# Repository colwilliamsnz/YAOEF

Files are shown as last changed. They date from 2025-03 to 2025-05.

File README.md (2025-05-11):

# YAOEF (Yet Another Open ESP Flasher)

## Status:

Tested. A PCB with this design has been built and tested.

## Introduction:

My remix of a simple "dongle" for flashing ESP32 based devices that have the ESPFlash header implemented (per Jon Oxer, SuperHouse. Ref http://superhouse.tv/espflash).

Why build USB capabilities into every ESP32 design when a simple header will suffice? Save on parts count, footprint, BOM, etc. The dongle supports auto-programming logic and a power switch allows it to be used for serial debugging when under circuit power (I.e., turn the switch off to disable USB power to ESPFlash header).

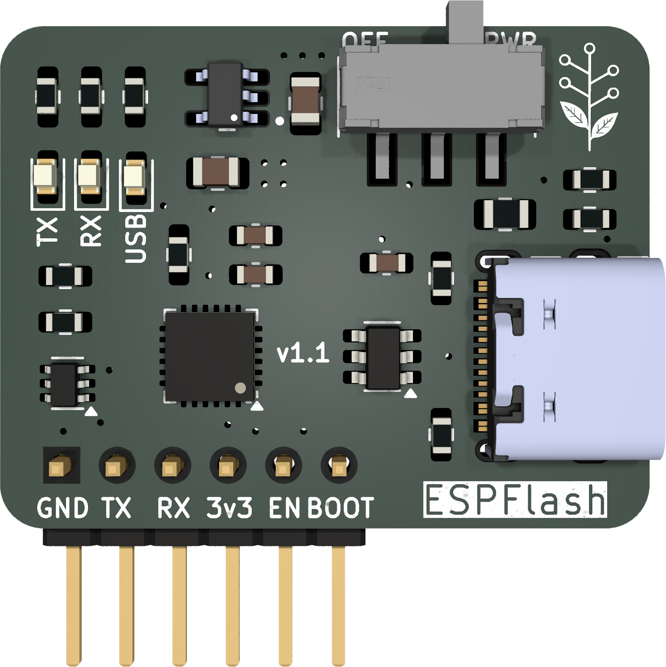
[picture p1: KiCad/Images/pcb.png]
Prototype


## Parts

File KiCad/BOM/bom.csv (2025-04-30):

Reference | Value | Footprint | Qty | Digikey_PN | Stocked
C1,C2 | 10u | Capacitor_SMD:C_0805_2012Metric | 2 | 490-6473-1-ND | Yes
C3,C5 | 100n | Capacitor_SMD:C_0603_1608Metric | 2 | 399-C0603C104K4RACTUCT-ND | Yes
C4 | 4.7u | Capacitor_SMD:C_0603_1608Metric | 1 | 1276-1784-1-ND
D1 | POWER | LED_SMD:LED_0603_1608Metric | 1 | 732-4978-1-ND | Yes
D2 | TX | LED_SMD:LED_0603_1608Metric | 1 | 732-4980-1-ND
D3 | RX | LED_SMD:LED_0603_1608Metric | 1 | 160-1434-1-ND
F1 | 6V 500mA | Fuse:Fuse_0805_2012Metric | 1 | 5923-0ZCK0050FF2ECT-ND
J1 | USB-C-16P (USB 2.0 only) | Wattle_Connectors:GCT_USB4105-GF-A-120 | 1 | 2073-USB4105-GF-A-120CT-ND
Q1 | MMDT3904 | Package_TO_SOT_SMD:SOT-363_SC-70-6 | 1 | 4786-MMDT3904CT-ND
R1 | 4k7 | Resistor_SMD:R_0603_1608Metric | 1 | 541-3993-1-ND | Yes
R2,R3 | 5k1 | Resistor_SMD:R_0603_1608Metric | 2 | 541-4030-1-ND
R4,R5,R6 | 1k | Resistor_SMD:R_0603_1608Metric | 3 | MCT0603-1.00K-MFCT-ND | Yes
R7,R8 | 10k | Resistor_SMD:R_0603_1608Metric | 2 | A121523CT-ND
R9 | 22k1 | Resistor_SMD:R_0603_1608Metric | 1 | 541-5271-1-ND
R10 | 47k5 | Resistor_SMD:R_0603_1608Metric | 1 | 541-4050-1-ND
S1 | JS102011SAQN | Wattle_Switches:SW_JS102011SAQN | 1 | 401-1999-1-ND
U1 | TLV75533PDBVR | Wattle_Regulators:TLV75533PDBVR | 1 | 296-50411-1-ND
U2 | USBLC6-4SC6 | Package_TO_SOT_SMD:SOT-23-6 | 1 | 497-4492-1-ND
U3 | CP2102N-Axx-xQFN24 | Package_DFN_QFN:QFN-24-1EP_4x4mm_P0.5mm_EP2.6x2.6mm | 1 | CP2102N-A02-GQFN24

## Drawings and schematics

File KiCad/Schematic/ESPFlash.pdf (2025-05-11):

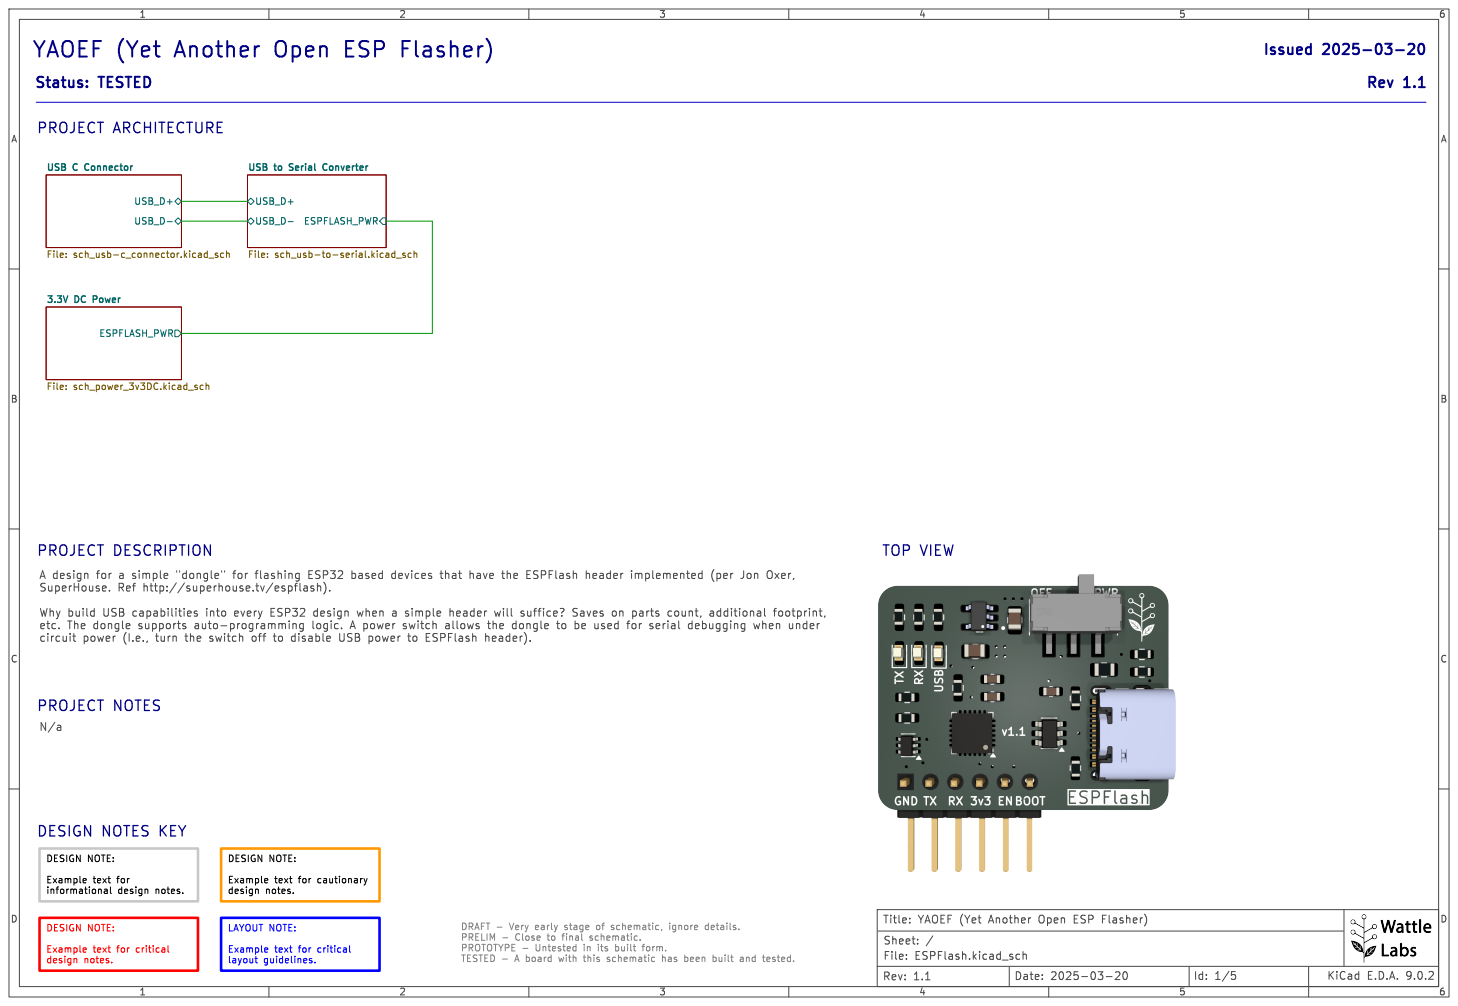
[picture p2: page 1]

3.3V DC Power File: sch_power_3v3DC.kicad_sch Revision History File: project history.kicad_sch

USB to Serial Converter File: sch_usb-to-serial.kicad_sch N/a

design notes. DESIGN NOTE: Example text for

DESIGN NOTE: Example text for cautionary

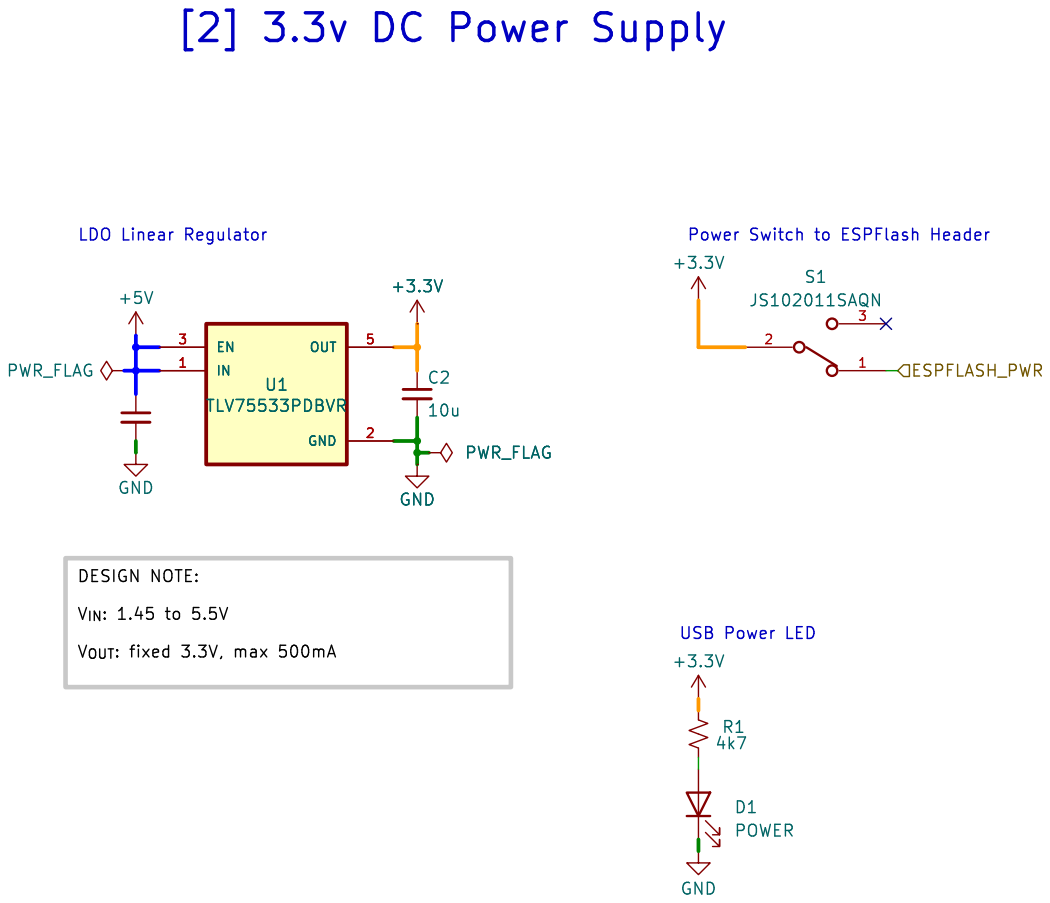
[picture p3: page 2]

DESIGN NOTE: V_{IN}:1.45 to 5.5V

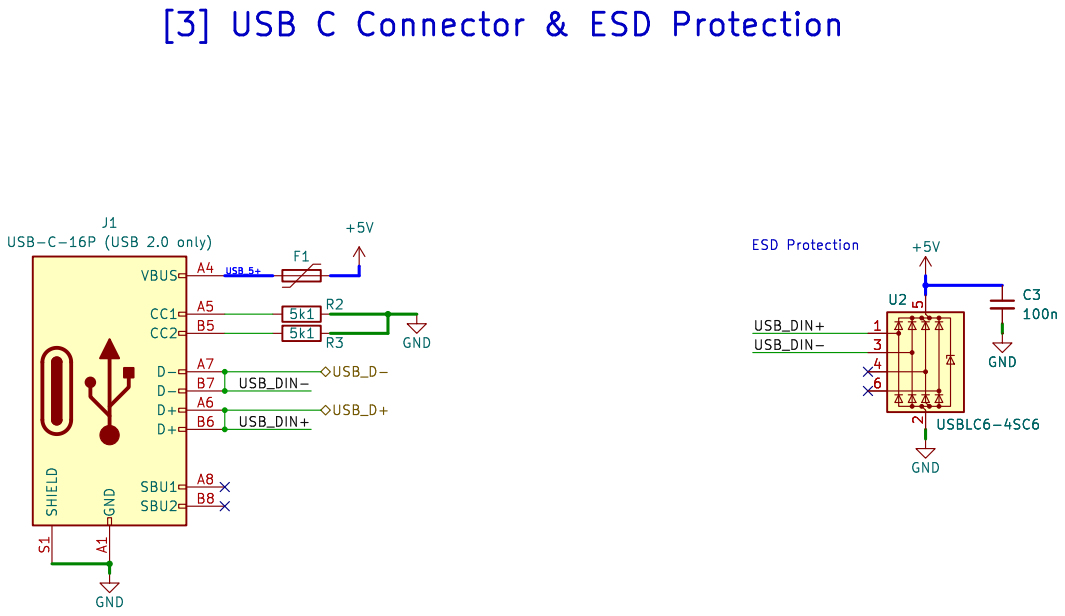
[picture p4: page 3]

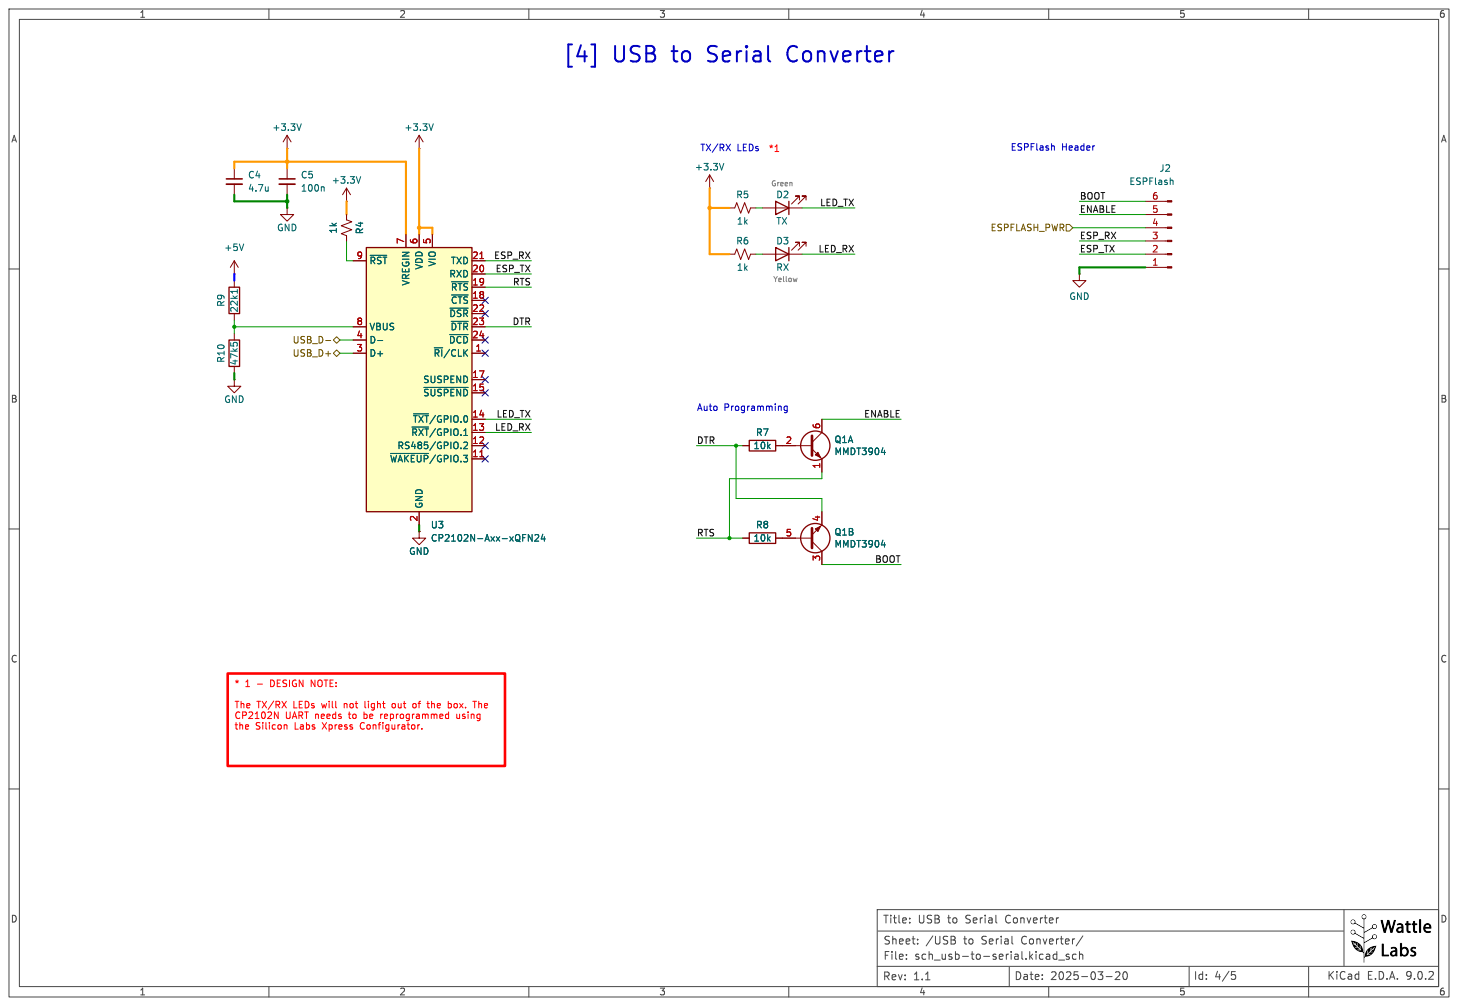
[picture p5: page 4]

TX/RX LEDs Auto Programming

5 TXD 21 RXD 20 ~{RTS} 19 ~{CTS} 18 ~{DSR} 22 ~{DTR} 23 ~{DCD} 24 ~{RI}/CLK1 SUSPEND 17 ~{SUSPEND}15 ~{TXT}/GPIO.014 ~{RXT}/GPIO.113 RS485/GPIO.2 12 ~{WAKEUP}/GPIO.311 U3 CP2102N-Axx-xQFN24 +3.3V GND GND

5 TXD 21 RXD 20 ~{RTS} 19 ~{CTS} 18 ~{DSR} 22 ~{DTR} 23 ~{DCD} 24 ~{RI}/CLK1 SUSPEND 17 ~{SUSPEND}15 ~{TXT}/GPIO.014 ~{RXT}/GPIO.113 RS485/GPIO.2 12 ~{WAKEUP}/GPIO.311 R7

the Silicon Labs Xpress Configurator. (https://community.silabs.com/s/question/0D58Y00008Q3vOSSAZ/cp2102na02gqfn24-gpio0-tx-led-gpio1-rx-led-not-working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)

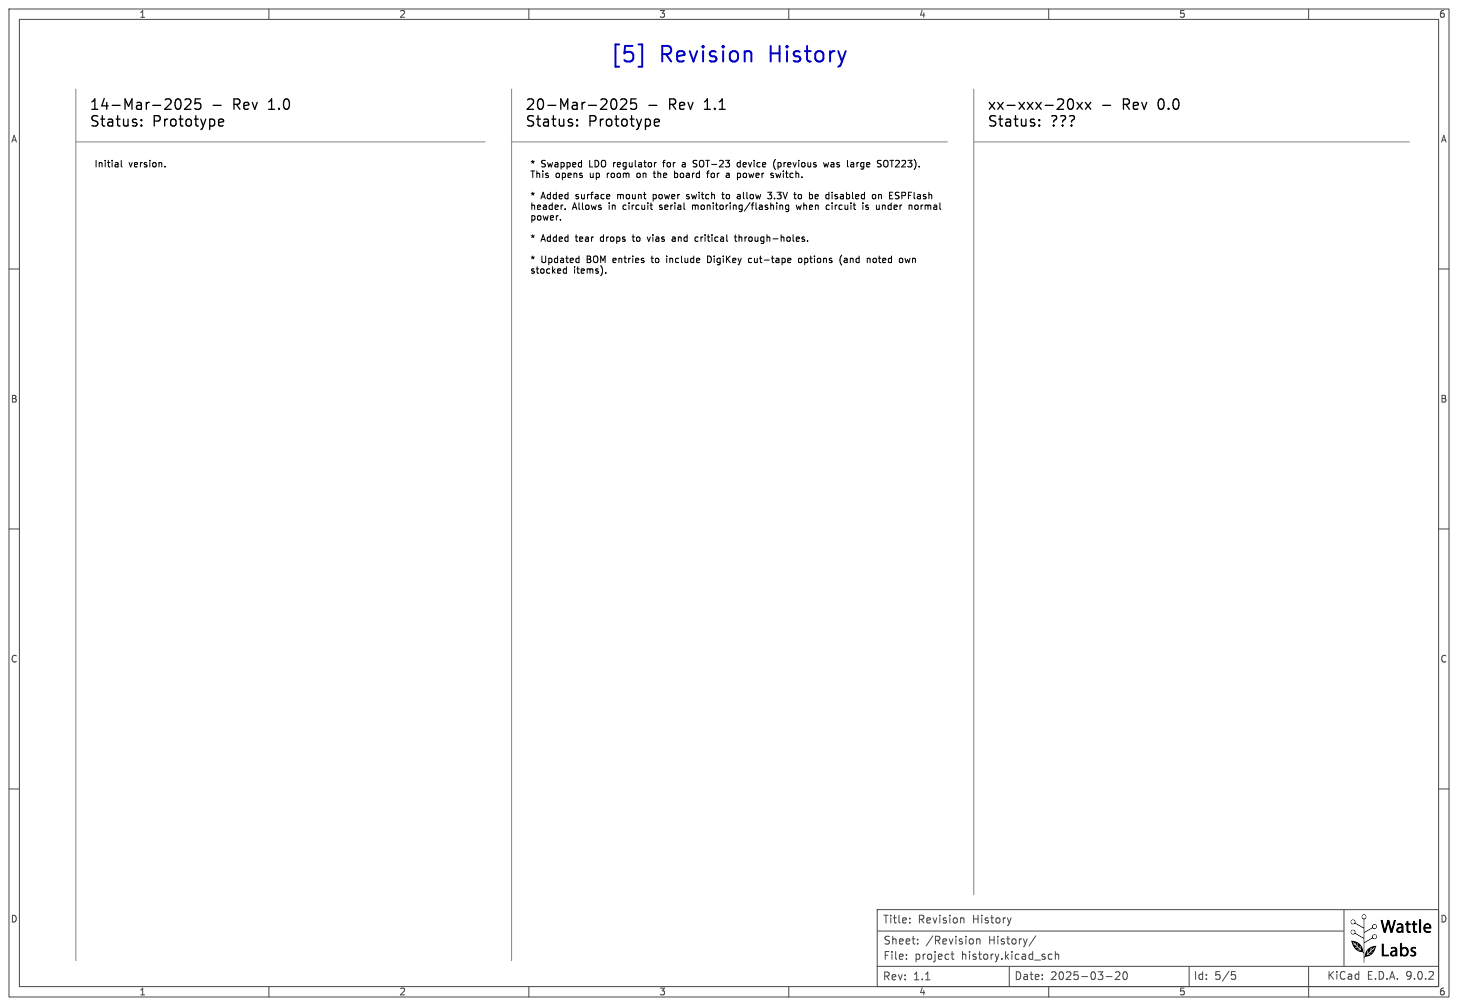
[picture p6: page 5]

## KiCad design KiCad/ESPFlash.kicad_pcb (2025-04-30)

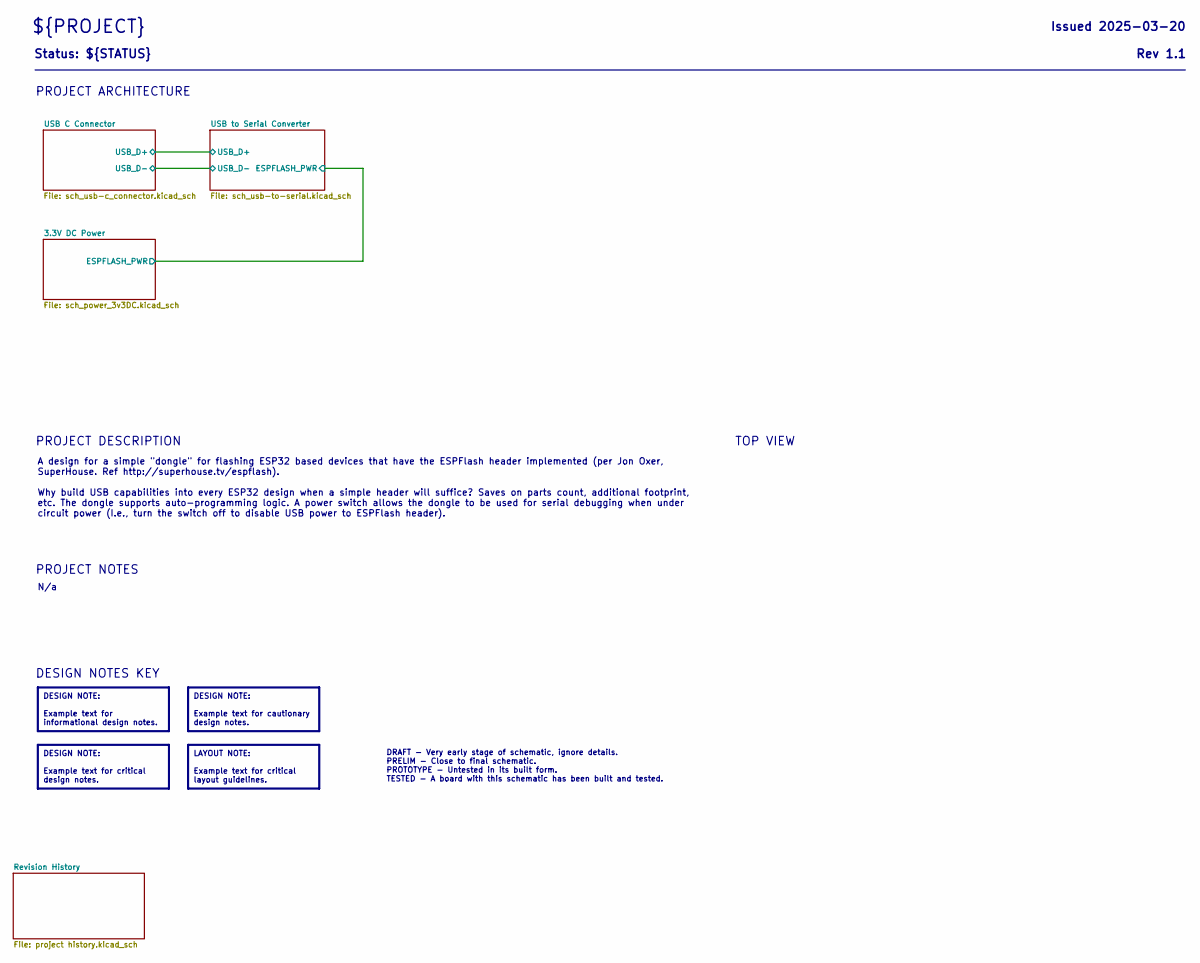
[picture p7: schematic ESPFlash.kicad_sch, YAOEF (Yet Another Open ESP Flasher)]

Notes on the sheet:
PROJECT DESCRIPTION
PROJECT NOTES
TOP VIEW
DESIGN NOTES KEY
PROJECT ARCHITECTURE
DESIGN NOTE: Example text for critical design notes.
DESIGN NOTE: Example text for informational design notes.
DESIGN NOTE: Example text for cautionary design notes.
Status: ${STATUS}
DRAFT - Very early stage of schematic, ignore details. PRELIM - Close to final schematic. PROTOTYPE - Untested in its built form. TESTED - A board with this schematic has been built and tested.
N/a
Rev ${REVISION}
A design for a simple "dongle" for flashing ESP32 based devices that have the ESPFlash header implemented (per Jon Oxer, SuperHouse. Ref http://superhouse.tv/espflash). Why build USB capabilities into every ESP32 design when a simple header will suffice? Saves on parts count, additional footprint, 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
${PROJECT}
LAYOUT NOTE: Example text for critical layout guidelines.
Issued ${ISSUE_DATE}

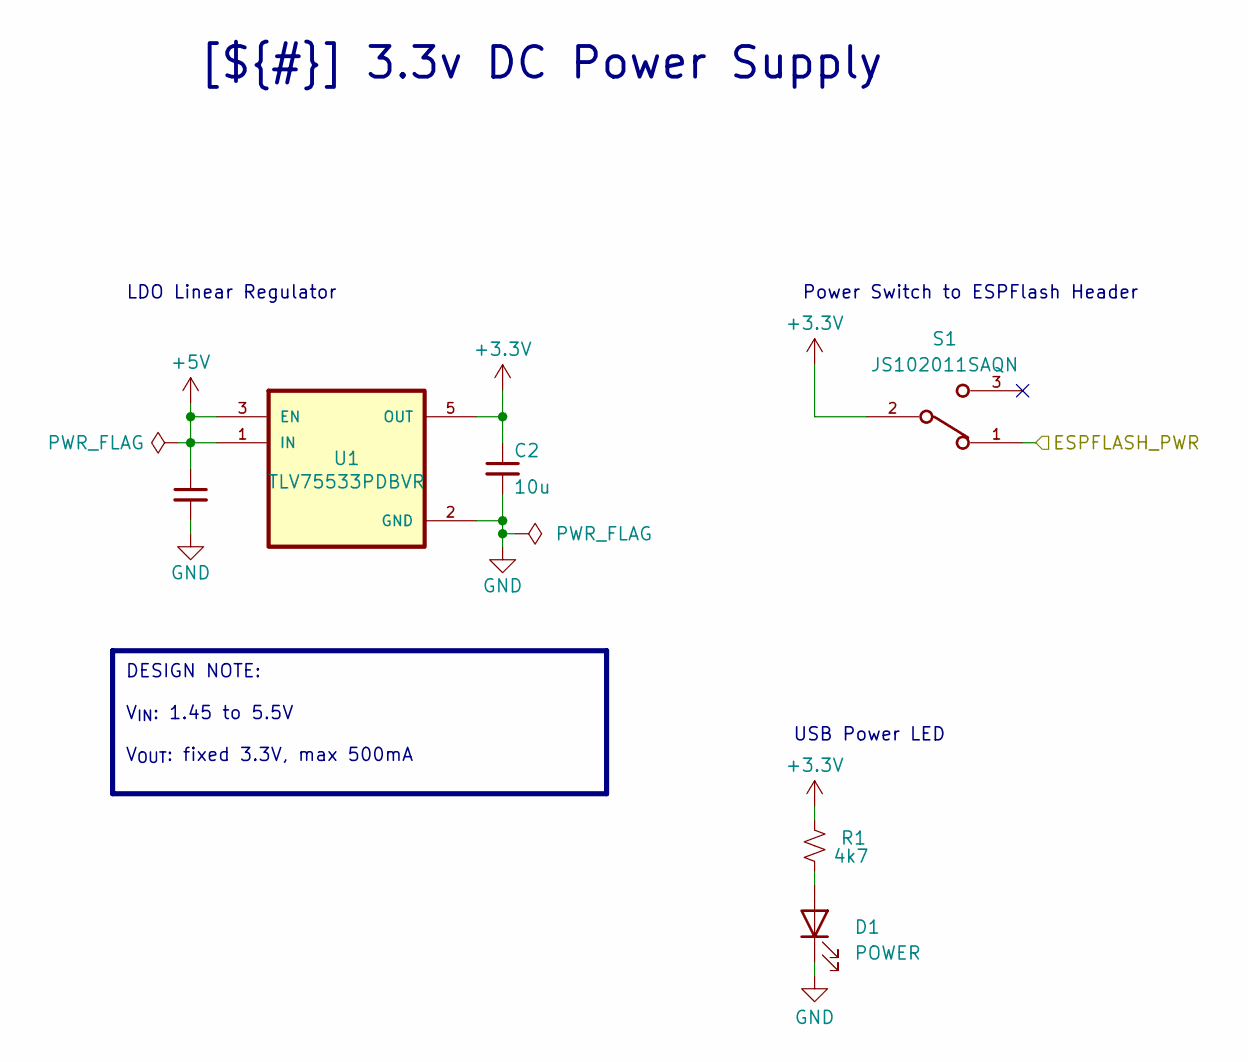
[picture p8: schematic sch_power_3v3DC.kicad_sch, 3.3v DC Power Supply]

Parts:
C1, C2: 10u; C_0805_2012Metric; Digikey_PN 490-6473-1-ND
D1: POWER; LED_0603_1608Metric; Digikey_PN 732-4978-1-ND
R1: 4k7; R_0603_1608Metric; Digikey_PN 541-3993-1-ND
S1: JS102011SAQN; SW_JS102011SAQN; Digikey_PN 401-1999-1-ND
U1: TLV75533PDBVR; Digikey_PN 296-50411-1-ND

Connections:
+3.3V: C2.1, R1.2, S1.2, U1.5 (OUT); also elsewhere on the board
+5V: C1.1, U1.1 (IN), U1.3 (EN); also elsewhere on the board
/3.3V DC Power/ESPFLASH_PWR: S1.1; also elsewhere on the board
GND: C1.2, C2.2, D1.1 (K), U1.2 (GND); also elsewhere on the board
unnamed: D1.2 (A), R1.1

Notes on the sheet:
Power Switch to ESPFlash Header
LDO Linear Regulator
USB Power LED
DESIGN NOTE: V_{IN}: 1.45 to 5.5V V_{OUT}: fixed 3.3V, max 500mA
[${#}] ${TITLE}

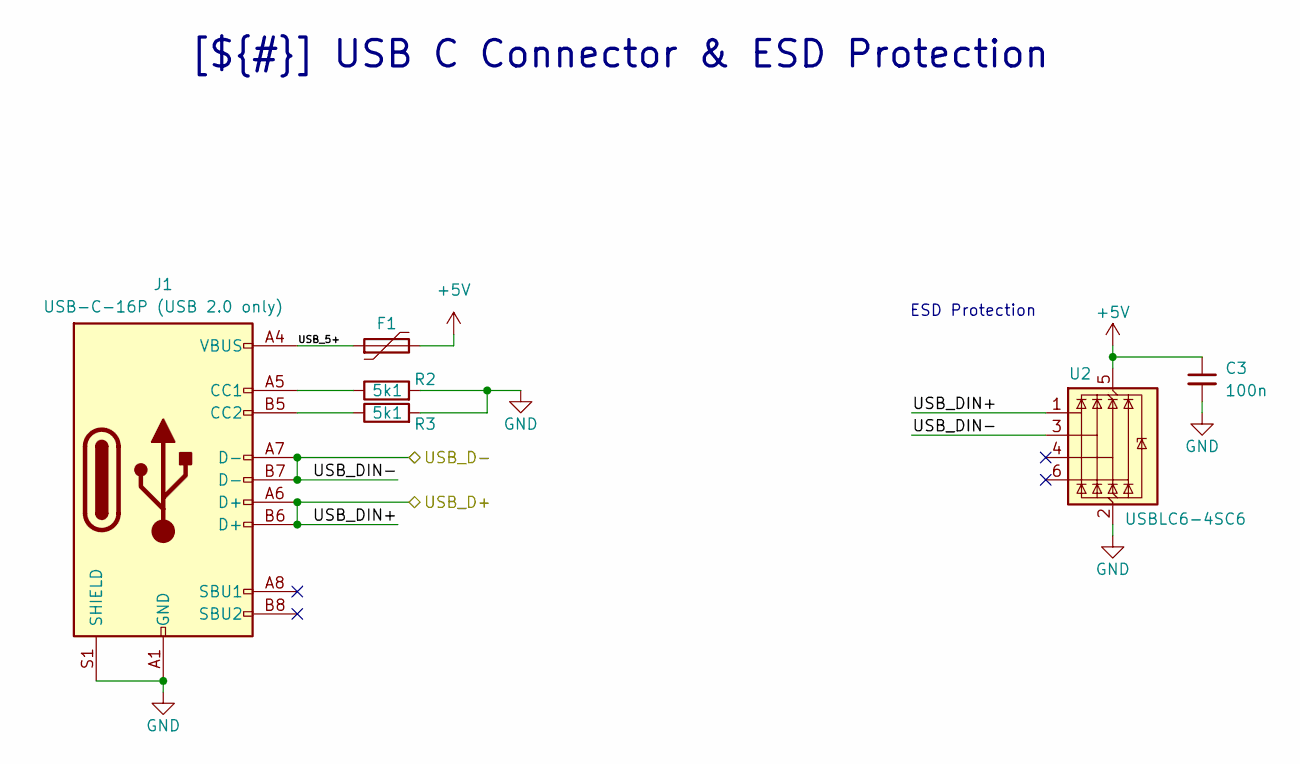
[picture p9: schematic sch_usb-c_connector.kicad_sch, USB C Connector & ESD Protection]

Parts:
C3: 100n; C_0603_1608Metric; Digikey_PN 399-C0603C104K4RACTUCT-ND
F1: 6V 500mA; Fuse_0805_2012Metric; Digikey_PN 5923-0ZCK0050FF2ECT-ND
J1: USB-C-16P (USB 2.0 only); GCT_USB4105-GF-A-120; Digikey_PN 2073-USB4105-GF-A-120CT-ND
R2, R3: 5k1; R_0603_1608Metric; Digikey_PN 541-4030-1-ND
U2: USBLC6-4SC6; SOT-23-6; Digikey_PN 497-4492-1-ND

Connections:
+5V: C3.1, F1.2, U2.5 (VBUS); also elsewhere on the board
/USB C Connector/USB_5+: F1.1, J1.A4 (VBUS), J1.A9 (VBUS), J1.B4 (VBUS), J1.B9 (VBUS)
/USB C Connector/USB_DIN+: J1.A6 (D+), J1.B6 (D+), U2.1 (I/O1); also elsewhere on the board
/USB C Connector/USB_DIN-: J1.A7 (D-), J1.B7 (D-), U2.3 (I/O2); also elsewhere on the board
GND: C3.2, J1.A1 (GND), J1.A12 (GND), J1.B1 (GND), J1.B12 (GND), J1.S1 (SHIELD), R2.2, R3.2, U2.2 (GND); also elsewhere on the board
unnamed: J1.A5 (CC1), R2.1
unnamed: J1.B5 (CC2), R3.1

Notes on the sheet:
ESD Protection
[${#}] ${TITLE}

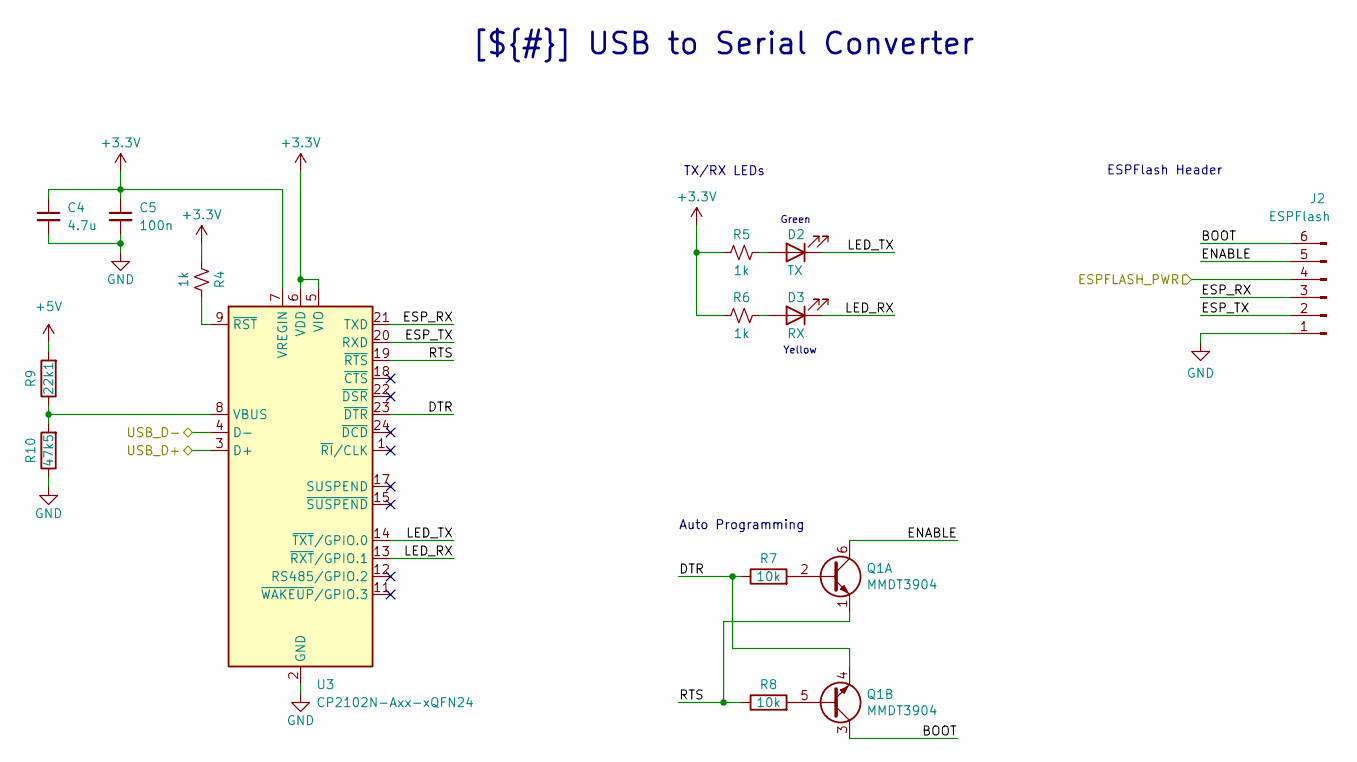
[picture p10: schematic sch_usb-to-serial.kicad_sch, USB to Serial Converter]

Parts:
C4: 4.7u; C_0603_1608Metric; Digikey_PN 1276-1784-1-ND
C5: 100n; C_0603_1608Metric; Digikey_PN 399-C0603C104K4RACTUCT-ND
D2: TX; LED_0603_1608Metric; Digikey_PN 732-4980-1-ND
D3: RX; LED_0603_1608Metric; Digikey_PN 160-1434-1-ND
J2: ESPFlash; PinHeader_1x06_P2.54mm_Horizontal
Q1: MMDT3904; SOT-363_SC-70-6; Digikey_PN 4786-MMDT3904CT-ND
R4, R5, R6: 1k; R_0603_1608Metric; Digikey_PN MCT0603-1.00K-MFCT-ND
R7, R8: 10k; R_0603_1608Metric; Digikey_PN A121523CT-ND
R9: 22k1; R_0603_1608Metric; Digikey_PN 541-5271-1-ND
R10: 47k5; R_0603_1608Metric; Digikey_PN 541-4050-1-ND
U3: CP2102N-Axx-xQFN24; QFN-24-1EP_4x4mm_P0.5mm_EP2.6x2.6mm; Digikey_PN CP2102N-A02-GQFN24

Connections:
+3.3V: C4.1, C5.1, R4.2, R5.2, R6.2, U3.5 (VIO), U3.6 (VDD), U3.7 (VREGIN); also elsewhere on the board
+5V: R9.2; also elsewhere on the board
/3.3V DC Power/ESPFLASH_PWR: J2.4; also elsewhere on the board
/USB C Connector/USB_DIN+: U3.3 (D+); also elsewhere on the board
/USB C Connector/USB_DIN-: U3.4 (D-); also elsewhere on the board
/USB to Serial Converter/BOOT: J2.6, Q1.3 (C2)
/USB to Serial Converter/DTR: Q1.4 (E2), R7.1, U3.23 (~DTR)
/USB to Serial Converter/ENABLE: J2.5, Q1.6 (C1)
/USB to Serial Converter/ESP_RX: J2.3, U3.21 (TXD)
/USB to Serial Converter/ESP_TX: J2.2, U3.20 (RXD)
/USB to Serial Converter/LED_RX: D3.1 (K), U3.13 (~RXT/GPIO.1)
/USB to Serial Converter/LED_TX: D2.1 (K), U3.14 (~TXT/GPIO.0)
/USB to Serial Converter/RTS: Q1.1 (E1), R8.1, U3.19 (~RTS)
GND: C4.2, C5.2, J2.1, R10.1, U3.2 (GND), U3.25 (GND); also elsewhere on the board
unnamed: D2.2 (A), R5.1
unnamed: D3.2 (A), R6.1
unnamed: Q1.2 (B1), R7.2
unnamed: Q1.5 (B2), R8.2
unnamed: R9.1, R10.2, U3.8 (VBUS)
unnamed: R4.1, U3.9 (~RST)

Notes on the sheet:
TX/RX LEDs
ESPFlash Header
Green
Yellow
Auto Programming
[${#}] ${TITLE}

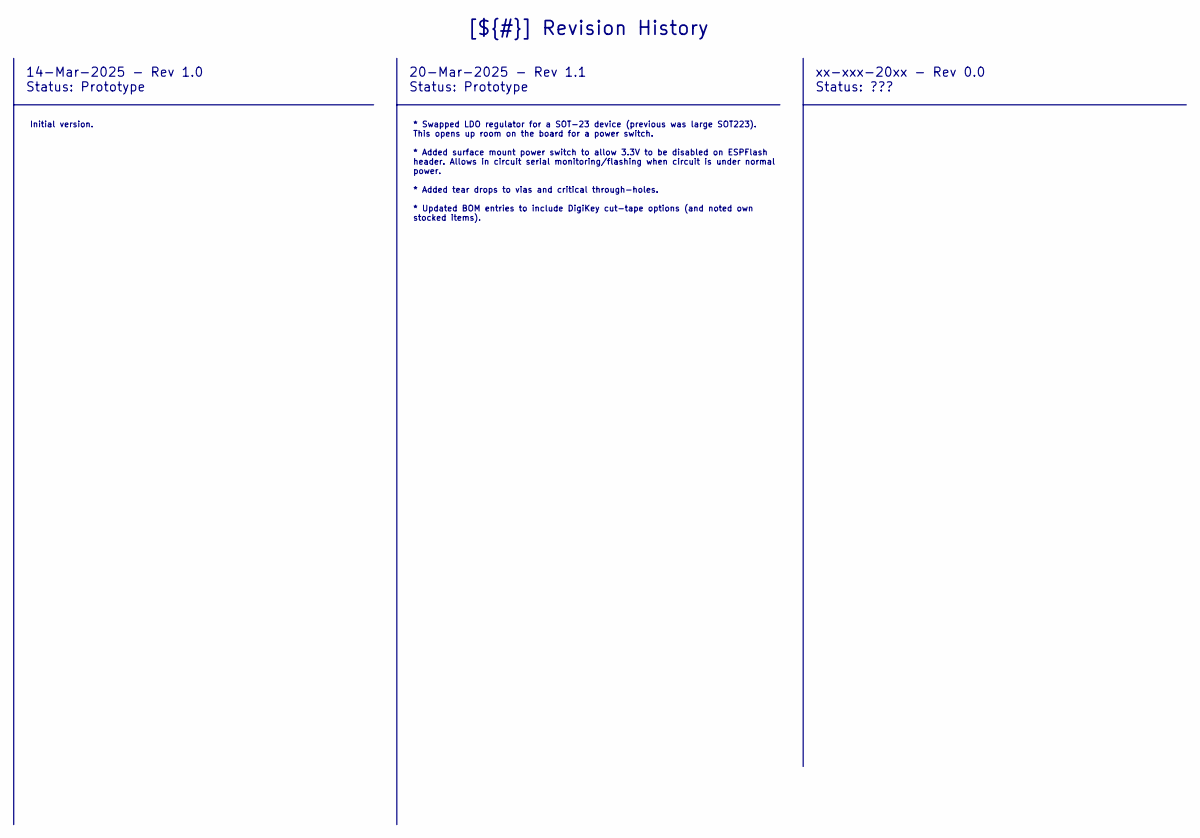
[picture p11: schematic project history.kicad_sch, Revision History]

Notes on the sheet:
14-Mar-2025 - Rev 1.0 Status: Prototype
20-Mar-2025 - Rev 1.1 Status: Prototype
xx-xxx-20xx - Rev 0.0 Status: ???
Initial version.
[${#}] ${TITLE}
* Swapped LDO regulator for a SOT-23 device (previous was large SOT223). This opens up room on the board for a power switch. * Added surface mount power switch to allow 3.3V to be disabled on ESPFlash header. Allows in circuit serial monitoring/flashing when circuit is under normal power. * Added t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

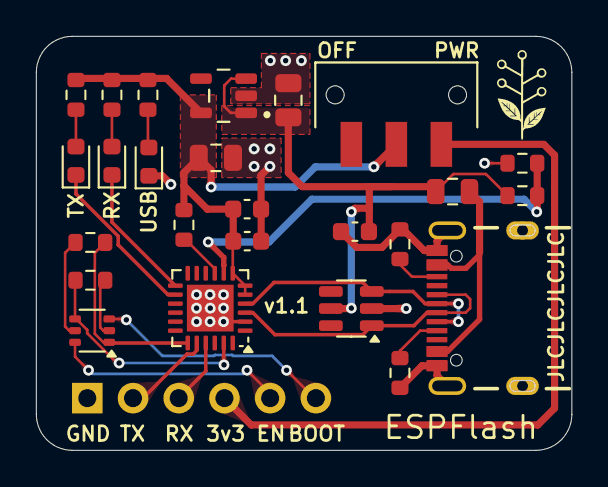
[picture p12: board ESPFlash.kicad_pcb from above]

Board: 2 copper layers, 29.8 x 23.0 mm, 26 parts (1 on the bottom side), 24 nets.

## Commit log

2025-03-20 Initial upload
    [ESPFlash.kicad_pcb, ESPFlash.kicad_sch, project history.kicad_sch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]
2025-03-20 Refactor directory structure for entire project
    Move KiCad files to subfolder. Makes Github entry point tidier :)
    [ESPFlash.kicad_pcb, ESPFlash.kicad_sch, project history.kicad_sch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]
2025-03-20 Update BoM
    Update components with full description and Digikey P/N.
    [ESPFlash.kicad_pcb, ESPFlash.kicad_sch, sch_power_3v3DC.kicad_sch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]
2025-04-30 Update BOM and general tidy-up
    Include DigiKey cut-tape components and add flag to indicate own stocked items. Remove files that aren't part of the sharable project (KiCad 9 embeds), Remove empty/irrelevant folders.
    [ESPFlash-B_Mask.gbs, ESPFlash-B_Paste.gbp, ESPFlash-B_Silkscreen.gbo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]
2025-05-11 Update project status to "Tested".
    [ESPFlash.kicad_sch, sch_usb-to-serial.kicad_sch]
